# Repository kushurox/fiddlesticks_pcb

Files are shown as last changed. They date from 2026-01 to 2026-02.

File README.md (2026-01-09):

# Fiddle Sticks

**Fiddle Sticks** is a hobby flight controller (FC) project I designed using an **STM32F411** MCU and lightweight **coreless motors**. This is my personal project to learn PCB design and get hands-on experience with embedded development.

## About

- **MCU:** STM32F411
- **Motors:** 8520 Coreless DC (brushed)
- **Sensor:** ICM-45605 (symbol from SnapEDA — you will need to download it from SnapEDA if you want to use it)
- **Purpose:** Hobby learning project for PCB design, firmware development, and embedded systems

## Project Goals

1. Learn PCB design workflow.
2. Interface STM32F411 with coreless motors and sensors.
3. Flash my own **Rust-written firmware** onto the board in the future.
4. Experiment with flight controller concepts in a low-risk hobby setting.

## Notes

- This is **not a production-ready drone FC** — it’s purely for learning and experimentation.
- If you want to use the ICM-45605 footprint/symbol, please get it from **[SnapEDA](https://www.snapeda.com/)**.

## License

This project is open for learning purposes. Check the LICENSE file for details.

---

> Hobby project by [kushurox](https://github.com/kushurox).

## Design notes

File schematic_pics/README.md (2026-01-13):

# Schematic Pictures

This folder contains the schematic diagrams for the Fiddle Sticks project.

> **Note:** GitHub may cache SVG images in README, so sometimes the displayed image might be outdated.  
> Clicking on the **raw link** below will always open the latest version.

---

## Block Diagram

Block Diagram

[View Block Diagram (raw)](https://raw.githubusercontent.com/kushurox/fiddlesticks_pcb/main/schematic_pics/fiddlesticks.svg)

---

## Power Flow Diagram

Power Flow Diagram

[View Power Flow Diagram (raw)](https://raw.githubusercontent.com/kushurox/fiddlesticks_pcb/main/schematic_pics/fiddlesticks-VBAT_to_5V.svg)

---

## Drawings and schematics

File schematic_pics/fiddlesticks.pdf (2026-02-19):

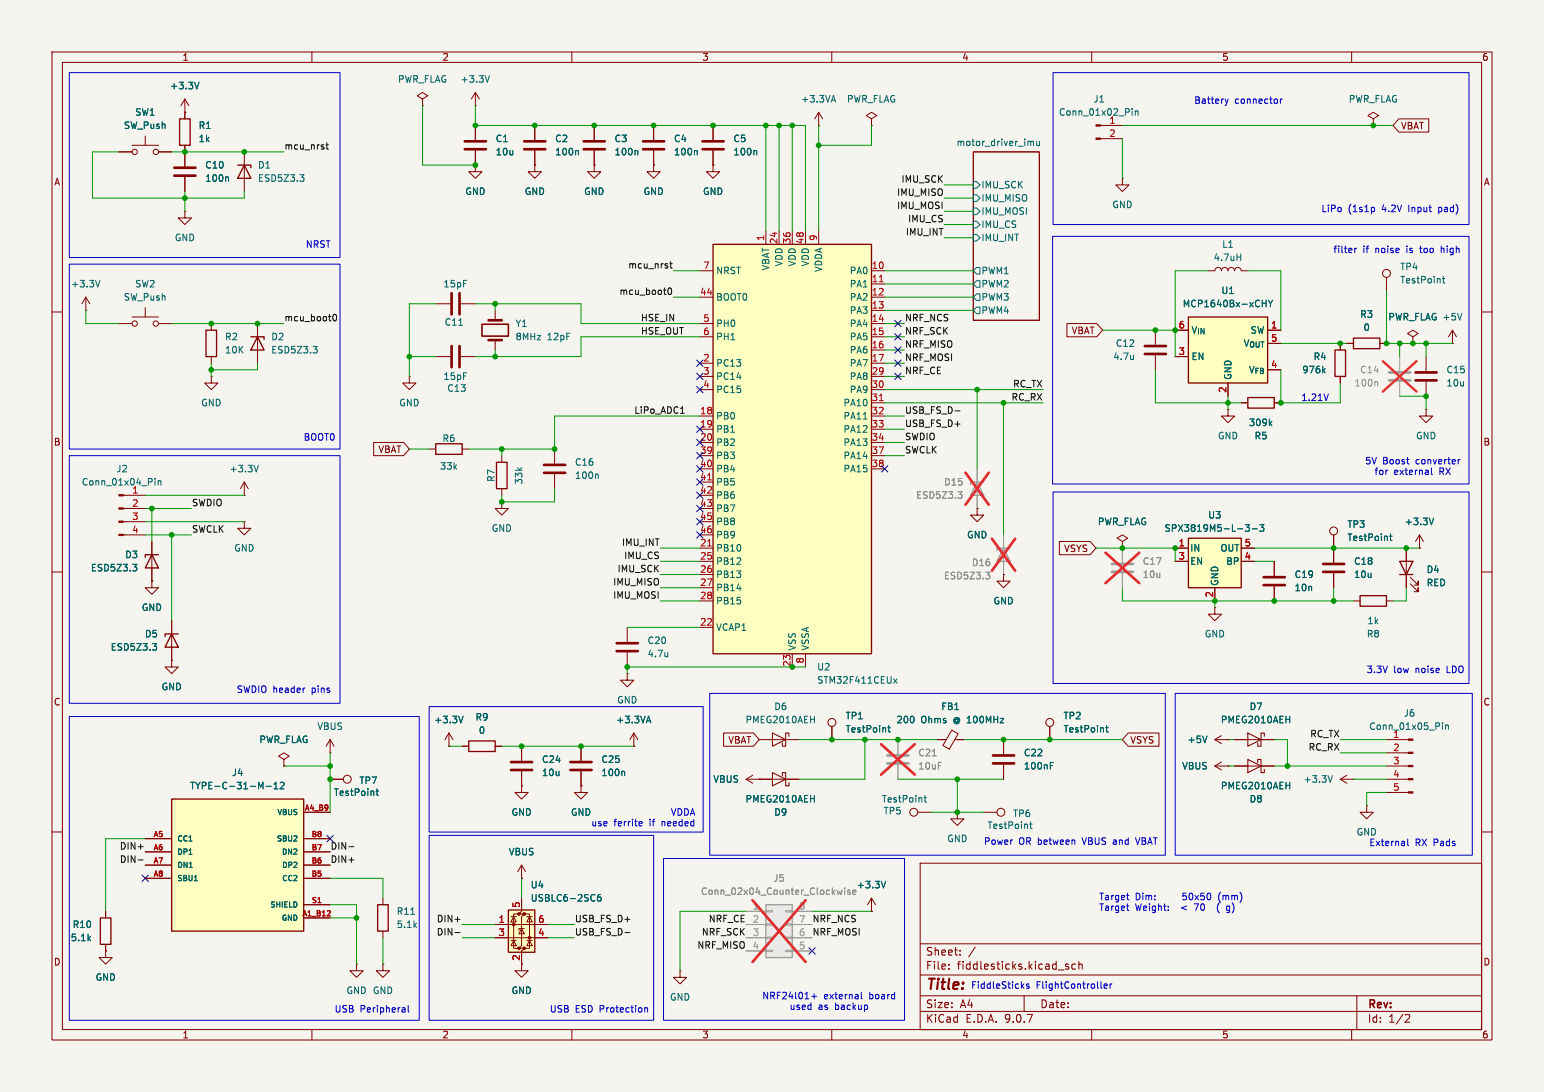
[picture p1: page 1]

LiPo (1s1p 4.2V Input pad) 5V Boost converter

1 VDD 24 VDD 36 VSS 23 VDD 48 VSSA

2 SW 1 V_{OUT} 5 V_{FB}4 U1 MCP1640Bx-xCHY

Id: 1/2 Title: File: fiddlesticks.kicad_sch Sheet: /

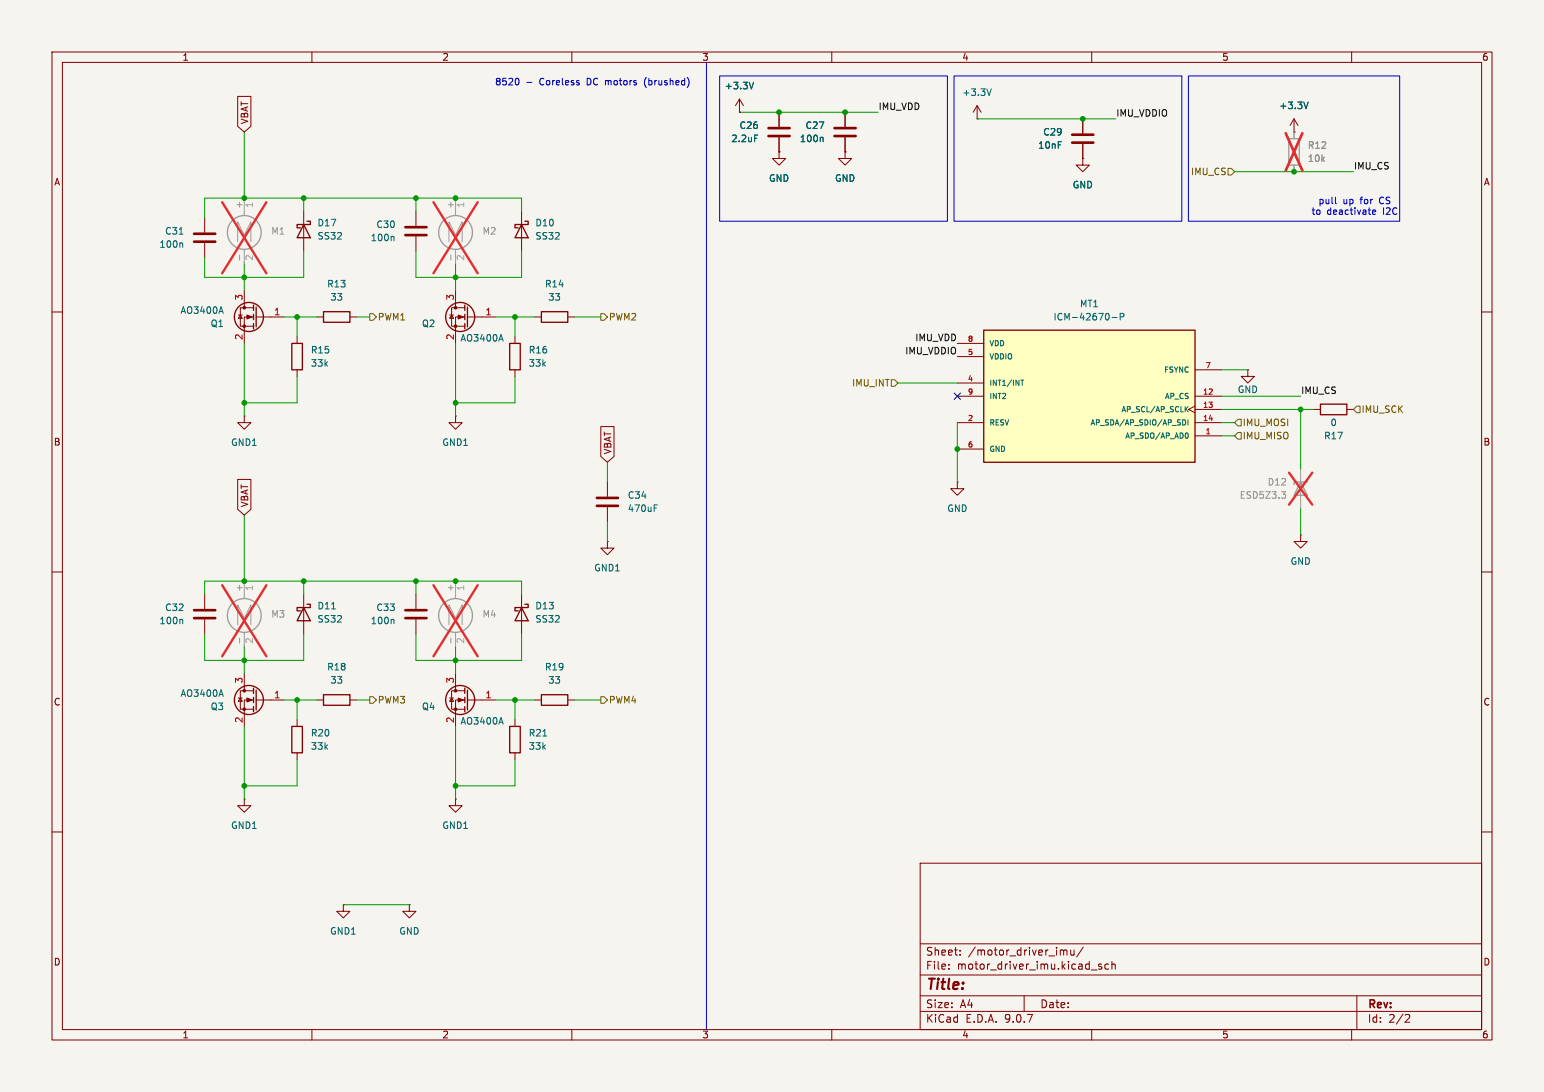
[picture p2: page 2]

pull up for CS

Id: 2/2 Title: File: motor_driver_imu.kicad_sch Sheet: /motor_driver_imu/ GND1 C30

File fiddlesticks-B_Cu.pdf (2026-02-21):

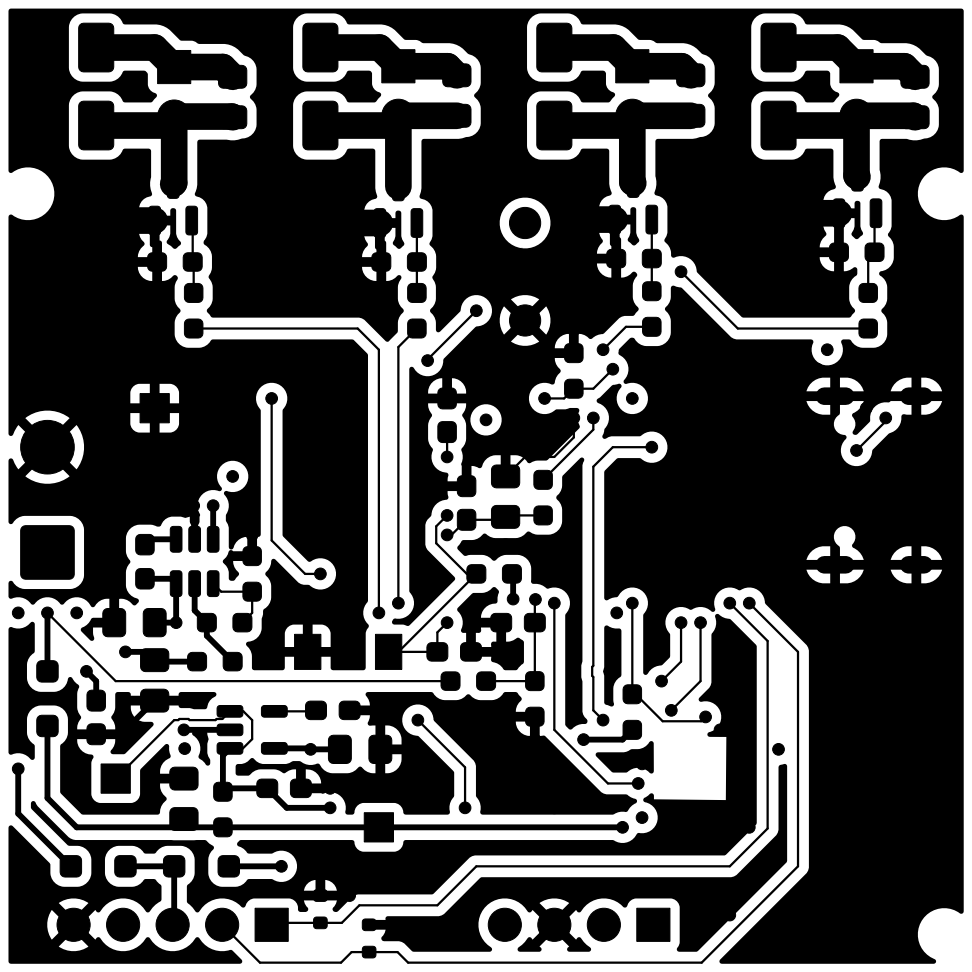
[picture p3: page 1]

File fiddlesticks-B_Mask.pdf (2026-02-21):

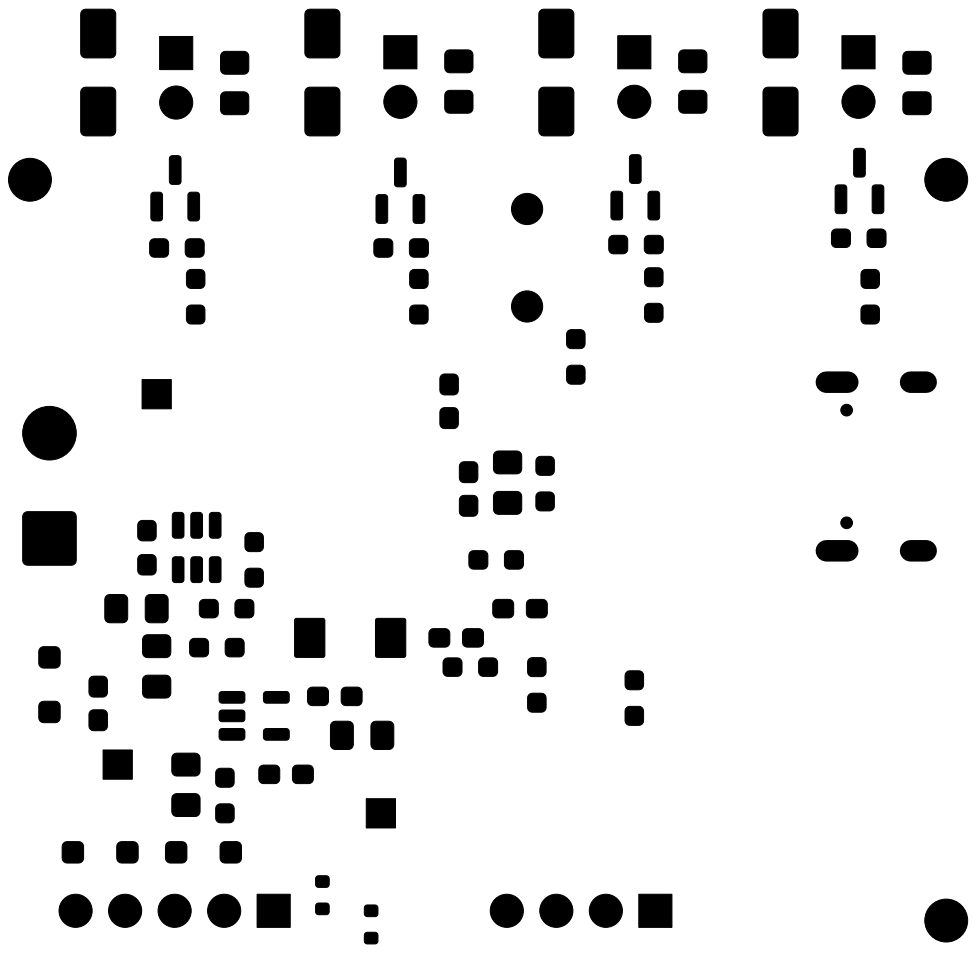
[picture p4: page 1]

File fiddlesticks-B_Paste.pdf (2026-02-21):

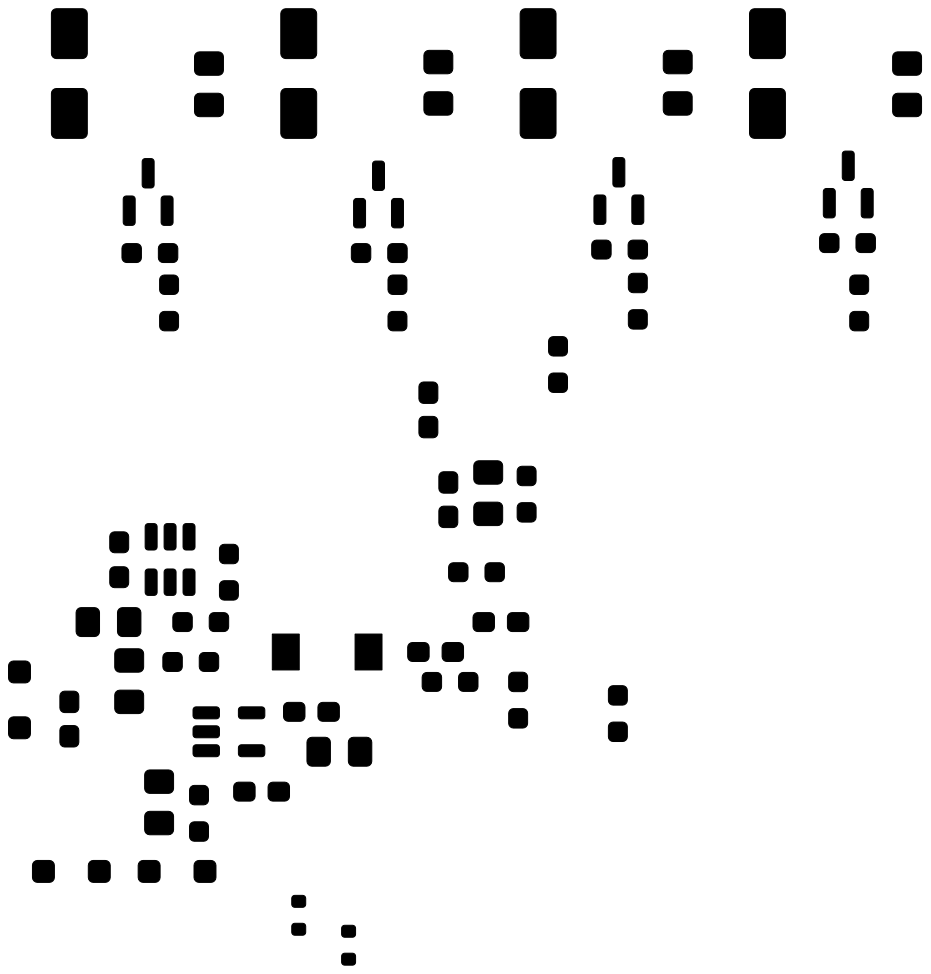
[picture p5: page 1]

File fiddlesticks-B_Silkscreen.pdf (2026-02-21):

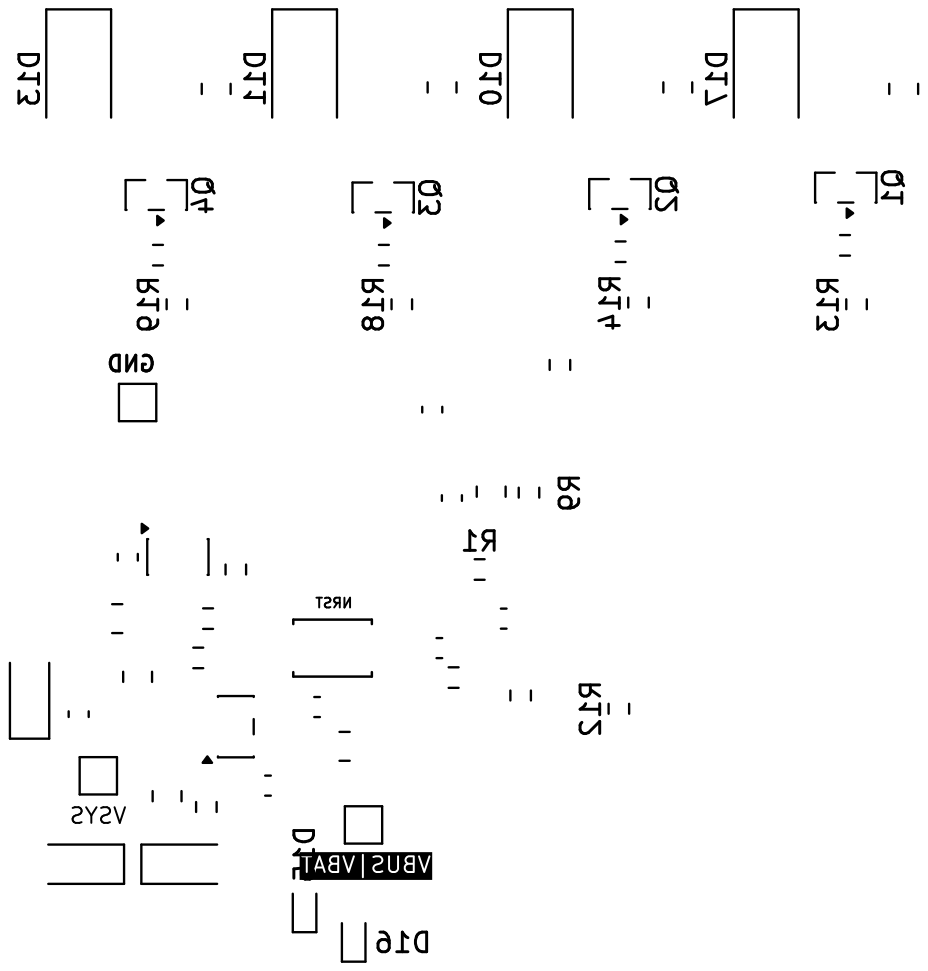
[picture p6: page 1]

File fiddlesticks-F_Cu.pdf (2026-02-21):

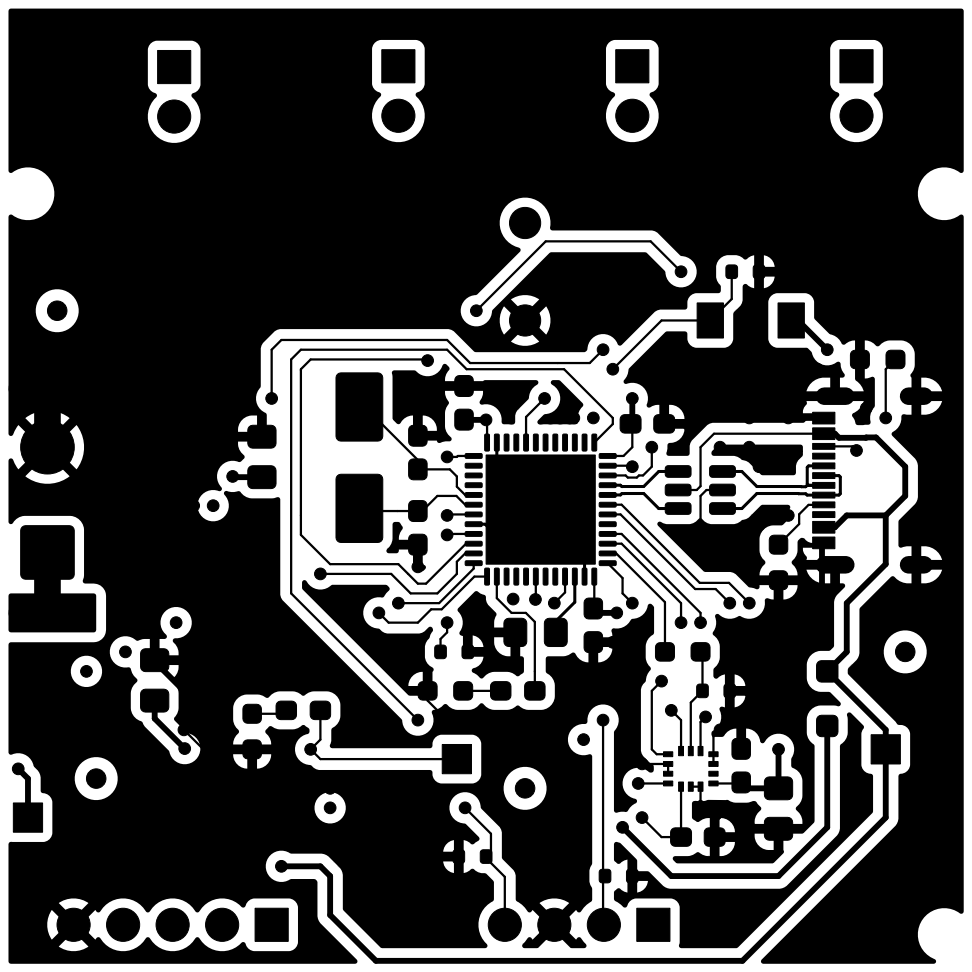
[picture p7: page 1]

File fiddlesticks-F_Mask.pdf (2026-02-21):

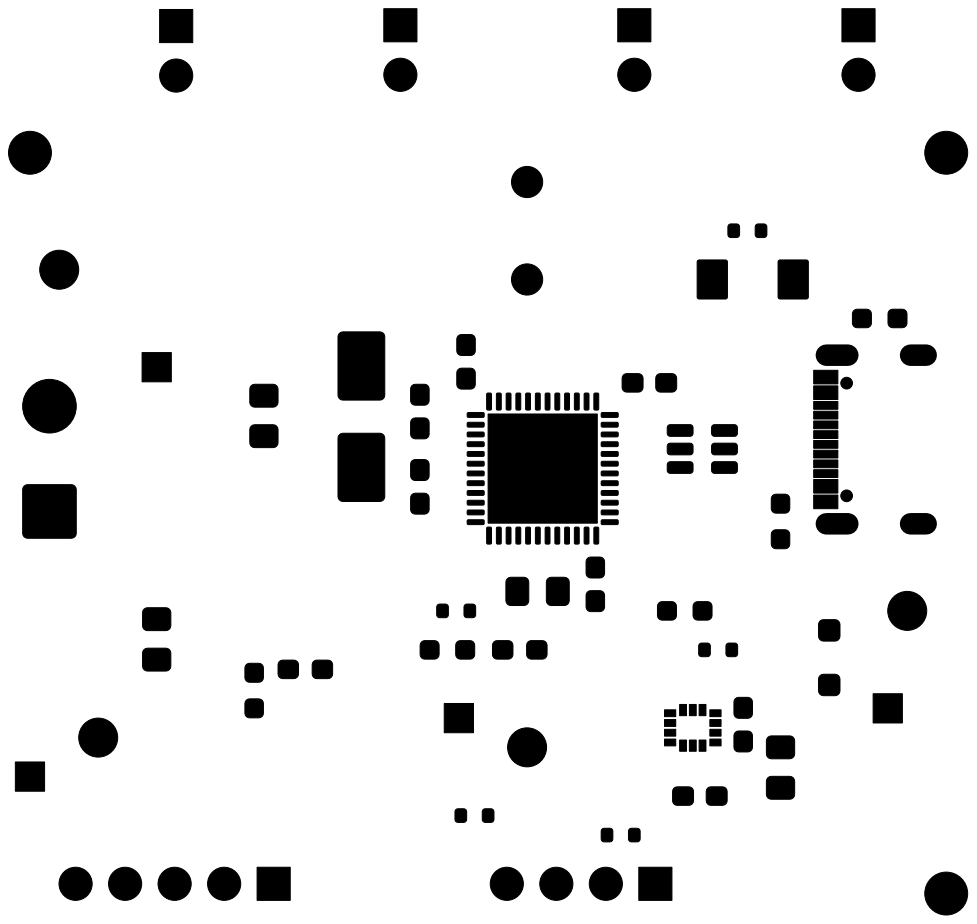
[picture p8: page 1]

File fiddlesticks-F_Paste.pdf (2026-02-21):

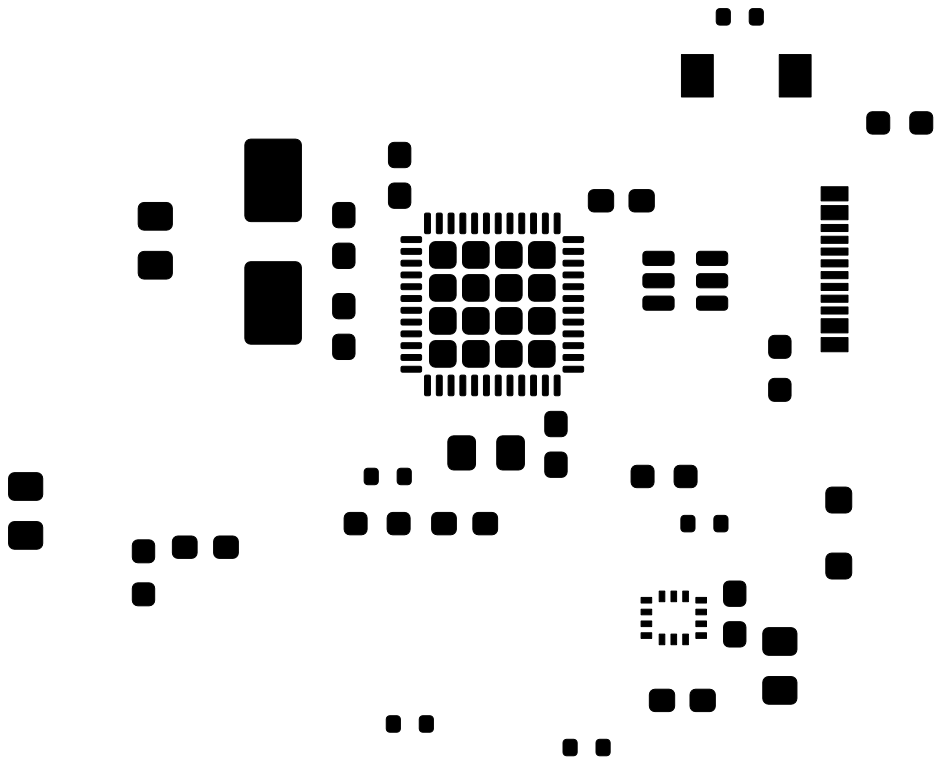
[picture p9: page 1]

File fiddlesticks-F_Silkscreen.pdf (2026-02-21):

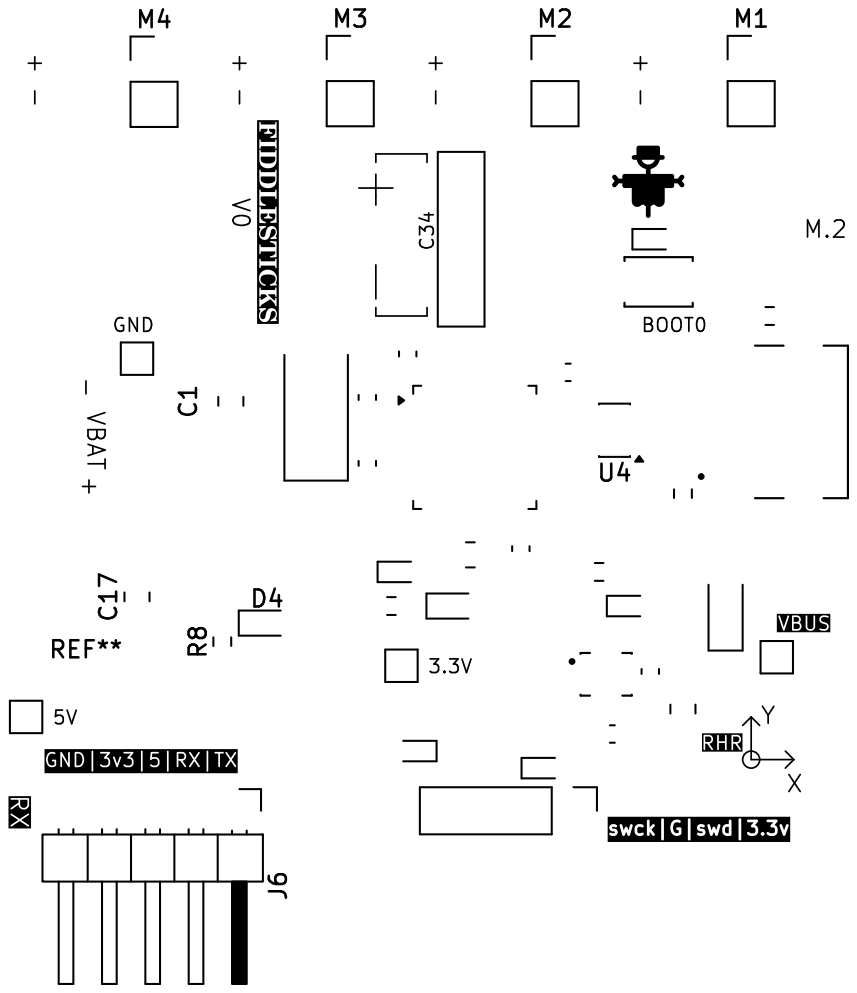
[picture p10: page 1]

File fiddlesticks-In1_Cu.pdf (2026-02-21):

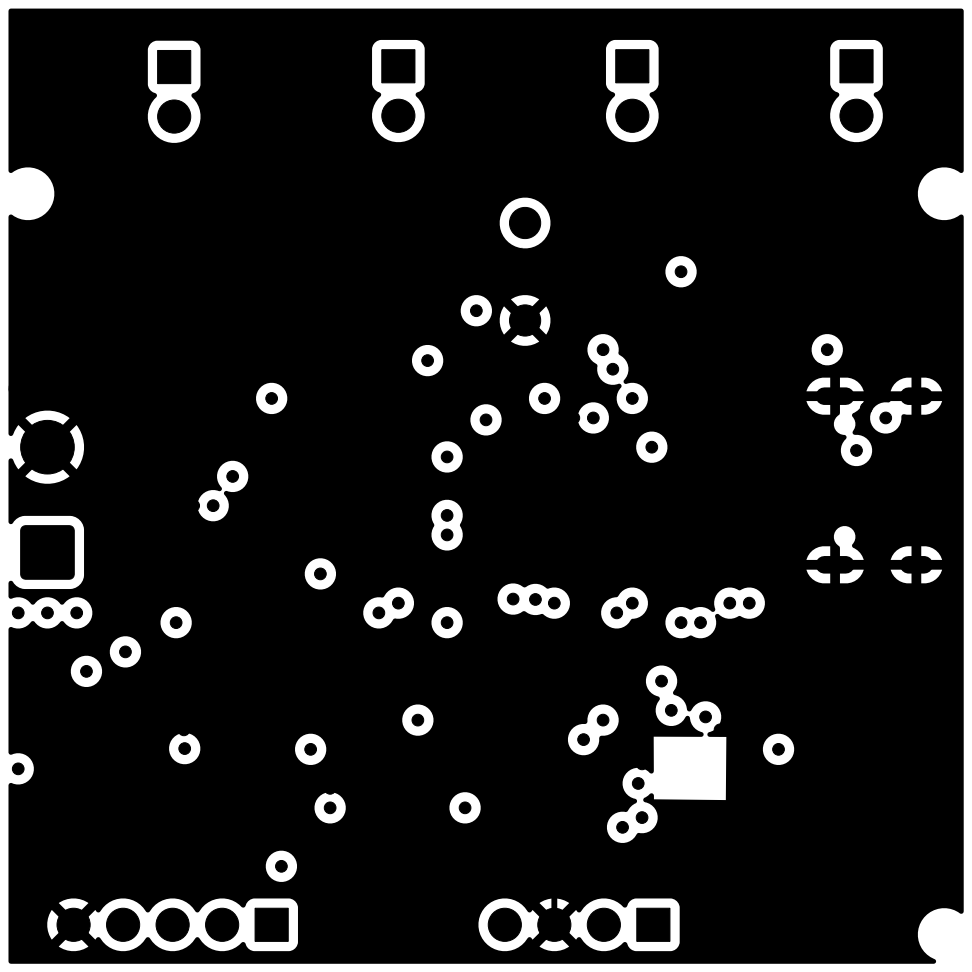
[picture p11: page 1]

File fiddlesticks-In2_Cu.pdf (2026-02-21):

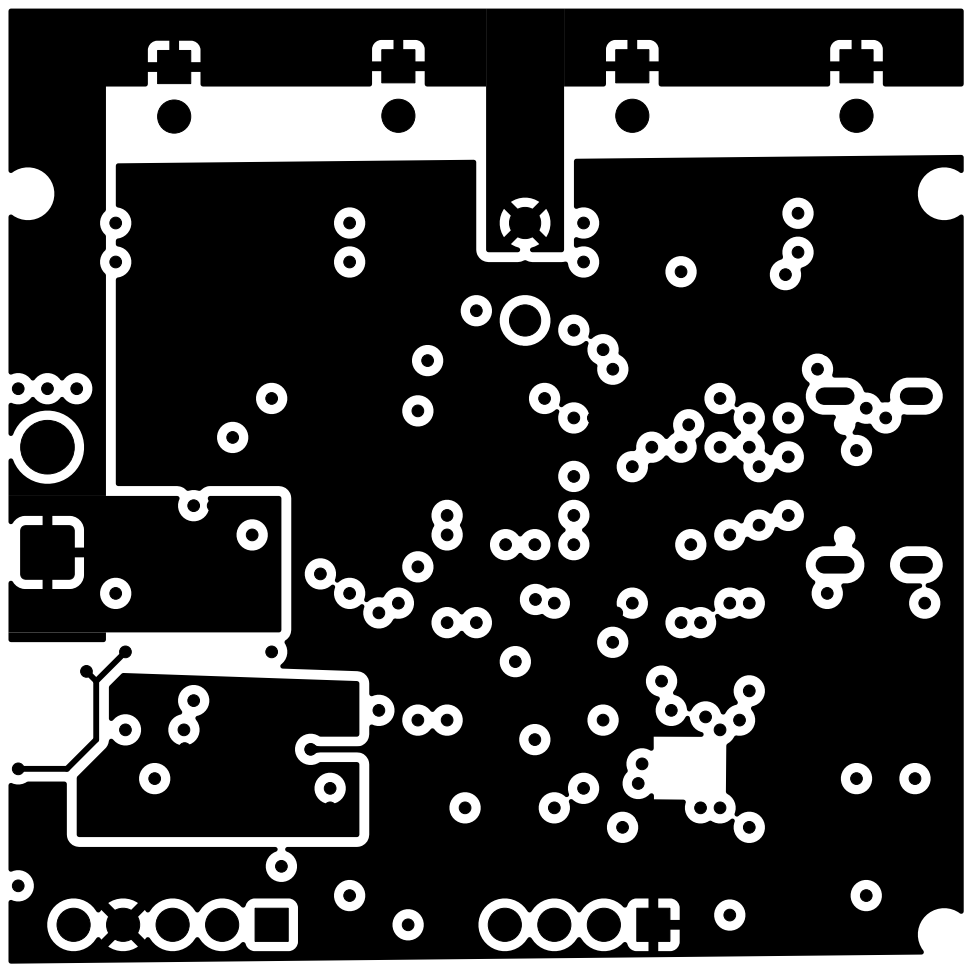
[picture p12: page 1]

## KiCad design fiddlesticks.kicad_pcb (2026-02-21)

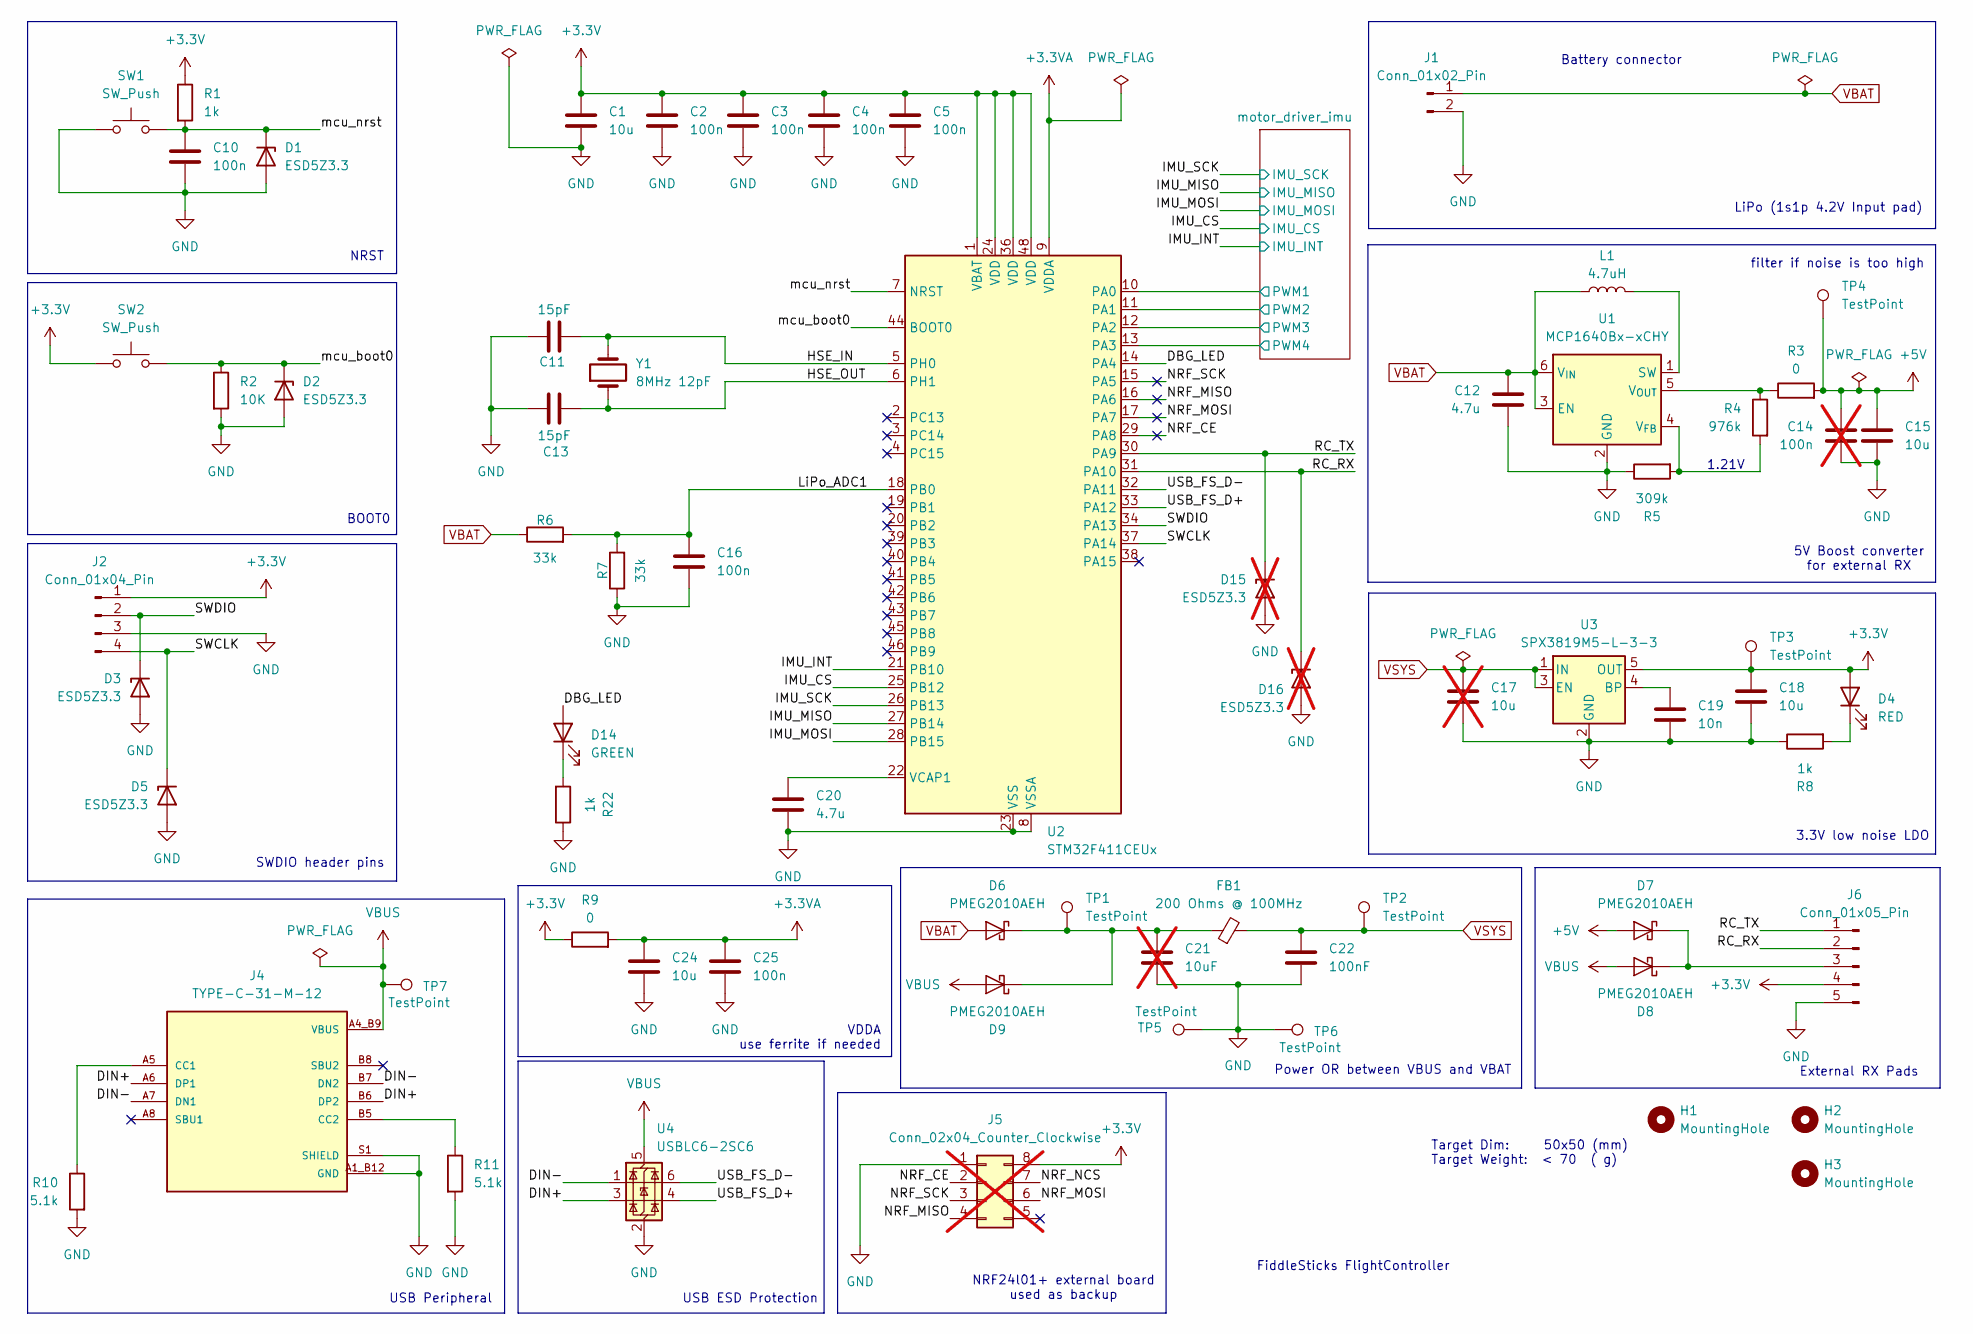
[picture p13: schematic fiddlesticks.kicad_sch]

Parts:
C1, C15, C18, C24: 10u; C_0805_2012Metric_Pad1.18x1.45mm_HandSolder
C2, C3, C4, C5, C10, C16, C25: 100n; C_0603_1608Metric_Pad1.08x0.95mm_HandSolder
C11, C13: 15pF; C_0603_1608Metric_Pad1.08x0.95mm_HandSolder
C12, C20: 4.7u; C_0805_2012Metric_Pad1.18x1.45mm_HandSolder
C14: 100n; C_0603_1608Metric_Pad1.08x0.95mm_HandSolder; not fitted
C17: 10u; C_0805_2012Metric_Pad1.18x1.45mm_HandSolder; not fitted
C19: 10n; C_0603_1608Metric_Pad1.08x0.95mm_HandSolder
C21: 10uF; C_0805_2012Metric_Pad1.18x1.45mm_HandSolder; not fitted
C22: 100nF; C_0603_1608Metric_Pad1.08x0.95mm_HandSolder
D1, D2, D3, D5: ESD5Z3.3; D_SOD-523
D4: RED; LED_0603_1608Metric_Pad1.05x0.95mm_HandSolder
D6, D7, D8, D9: PMEG2010AEH; D_SOD-123F
D14: GREEN; LED_0603_1608Metric_Pad1.05x0.95mm_HandSolder
D15, D16: ESD5Z3.3; D_SOD-523; not fitted
FB1: 200 Ohms @ 100MHz; R_0603_1608Metric_Pad0.98x0.95mm_HandSolder
H1, H2, H3: MountingHole; MountingHole_2.2mm_M2
J1: Conn_01x02_Pin; SolderWire-1sqmm_1x02_P5.4mm_D1.4mm_OD2.7mm
J2: Conn_01x04_Pin; PinHeader_1x04_P2.54mm_Vertical
J4: TYPE-C-31-M-12; HRO_TYPE-C-31-M-12; PARTREV 2020.12.08
J5: Conn_02x04_Counter_Clockwise; PinSocket_2x04_P2.54mm_Vertical; not fitted
J6: Conn_01x05_Pin; PinHeader_1x05_P2.54mm_Horizontal
L1: 4.7uH; L_0603_1608Metric_Pad1.05x0.95mm_HandSolder; MPN LQM18PN4R7MFRL
R1, R8, R22: 1k; R_0603_1608Metric_Pad0.98x0.95mm_HandSolder
R2: 10K; R_0603_1608Metric_Pad0.98x0.95mm_HandSolder
R3, R9: 0; R_0603_1608Metric_Pad0.98x0.95mm_HandSolder
R4: 976k; R_0603_1608Metric_Pad0.98x0.95mm_HandSolder
R5: 309k; R_0603_1608Metric_Pad0.98x0.95mm_HandSolder
R6, R7: 33k; R_0603_1608Metric_Pad0.98x0.95mm_HandSolder
R10, R11: 5.1k; R_0603_1608Metric_Pad0.98x0.95mm_HandSolder
SW1, SW2: SW_Push; SW_TS-1088-AR02016; MPN TS-1088-AR02016
TP1, TP2, TP3, TP4, TP5, TP6, TP7: TestPoint; TestPoint_Pad_1.5x1.5mm
U1: MCP1640Bx-xCHY; SOT-23-6
U2: STM32F411CEUx; QFN-48-1EP_7x7mm_P0.5mm_EP5.6x5.6mm
U3: SPX3819M5-L-3-3; SOT-23-5
U4: USBLC6-2SC6; SOT-23-6
Y1: 8MHz 12pF; Crystal_SMD_5032-2Pin_5.0x3.2mm_HandSoldering

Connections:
+3.3V: C1.1, C2.1, C3.1, C4.1, C5.1, C18.1, D4.2 (A), J2.1, J5.8, J6.4, R1.1, R9.1, SW2.1, TP3.1, U2.1 (VBAT), U2.24 (VDD), U2.36 (VDD), U2.48 (VDD), U3.5 (OUT); also elsewhere on the board
+3.3VA: C24.1, C25.1, R9.2, U2.9 (VDDA)
+5V: C14.1, C15.1, D7.2 (A), R3.2, TP4.1
/DBG_LED: D14.2 (A), U2.14 (PA4)
/DIN+: J4.A6 (DP1), J4.B6 (DP2), U4.3 (I/O2)
/DIN-: J4.A7 (DN1), J4.B7 (DN2), U4.1 (I/O1)
/HSE_IN: C11.1, U2.5 (PH0), Y1.2
/HSE_OUT: C13.2, U2.6 (PH1), Y1.1
/IMU_CS: U2.25 (PB12); also elsewhere on the board
/IMU_INT: U2.21 (PB10); also elsewhere on the board
/IMU_MISO: U2.27 (PB14); also elsewhere on the board
/IMU_MOSI: U2.28 (PB15); also elsewhere on the board
/IMU_SCK: U2.26 (PB13); also elsewhere on the board
/LiPo_ADC1: C16.1, R6.2, R7.2, U2.18 (PB0)
/NRF_CE: J5.2, U2.29 (PA8)
/NRF_MISO: J5.4, U2.16 (PA6)
/NRF_MOSI: J5.6, U2.17 (PA7)
/NRF_SCK: J5.3, U2.15 (PA5)
/RC_RX: D16.1 (K), J6.2, U2.31 (PA10)
/RC_TX: D15.1 (K), J6.1, U2.30 (PA9)
/SWCLK: D5.1 (K), J2.4, U2.37 (PA14)
/SWDIO: D3.1 (K), J2.2, U2.34 (PA13)
/USB_FS_D+: U2.33 (PA12), U4.4 (I/O2)
/USB_FS_D-: U2.32 (PA11), U4.6 (I/O1)
/mcu_boot0: D2.1 (K), R2.1, SW2.2, U2.44 (BOOT0)
/mcu_nrst: C10.1, D1.1 (K), R1.2, SW1.2, U2.7 (NRST)
/motor_driver_imu/PWM1: U2.10 (PA0); also elsewhere on the board
/motor_driver_imu/PWM2: U2.11 (PA1); also elsewhere on the board
/motor_driver_imu/PWM3: U2.12 (PA2); also elsewhere on the board
/motor_driver_imu/PWM4: U2.13 (PA3); also elsewhere on the board
GND: C1.2, C2.2, C3.2, C4.2, C5.2, C10.2, C11.2, C12.2, C13.1, C14.2, C15.2, C16.2, C17.2, C18.2, C19.2, C20.2, C21.2, C22.2, C24.2, C25.2, D1.2 (A), D2.2 (A), D3.2 (A), D5.2 (A), D15.2 (A), D16.2 (A), J1.2, J2.3, J4.A1_B12 (GND), J4.B1_A12 (GND), J4.S1 (SHIELD), J4.S2 (SHIELD), J4.S3 (SHIELD), J4.S4 (SHIELD), J5.1, J6.5, R2.2, R5.1, R7.1, R8.1, R10.2, R11.2, R22.1, SW1.1, TP5.1, TP6.1, U1.2 (GND), U2.8 (VSSA), U2.23 (VSS), U2.35 (VSS), U2.47 (VSS), U2.49 (VSS), U3.2 (GND), U4.2 (GND); also elsewhere on the board
unnamed: D4.1 (K), R8.2
unnamed: C21.1, D6.1 (K), D9.1 (K), FB1.1, TP1.1
unnamed: D7.1 (K), D8.1 (K), J6.3
unnamed: D14.1 (K), R22.2
unnamed: J4.A5 (CC1), R10.1
unnamed: J4.B5 (CC2), R11.1
unnamed: L1.2, U1.1 (SW)
unnamed: R4.2, R5.2, U1.4 (V_{FB})
unnamed: R3.1, R4.1, U1.5 (V_{OUT})
unnamed: C20.1, U2.22 (VCAP1)
unnamed: C19.1, U3.4 (BP)
VBAT: C12.1, D6.2 (A), J1.1, L1.1, R6.1, U1.3 (EN), U1.6 (V_{IN}); also elsewhere on the board
VBUS: D8.2 (A), D9.2 (A), J4.A4_B9 (VBUS), J4.B4_A9 (VBUS), TP7.1, U4.5 (VBUS)
VSYS: C17.1, C22.1, FB1.2, TP2.1, U3.1 (IN), U3.3 (EN)

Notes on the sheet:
LiPo (1s1p 4.2V Input pad)
USB Peripheral
3.3V low noise LDO
SWDIO header pins
USB ESD Protection
External RX Pads
NRF24l01+ external board used as backup
5V Boost converter for external RX
1.21V
NRST
Power OR between VBUS and VBAT
FiddleSticks FlightController
Target Dim: 50x50 (mm) Target Weight: < 70 ( g)
filter if noise is too high
Battery connector
VDDA use ferrite if needed
BOOT0

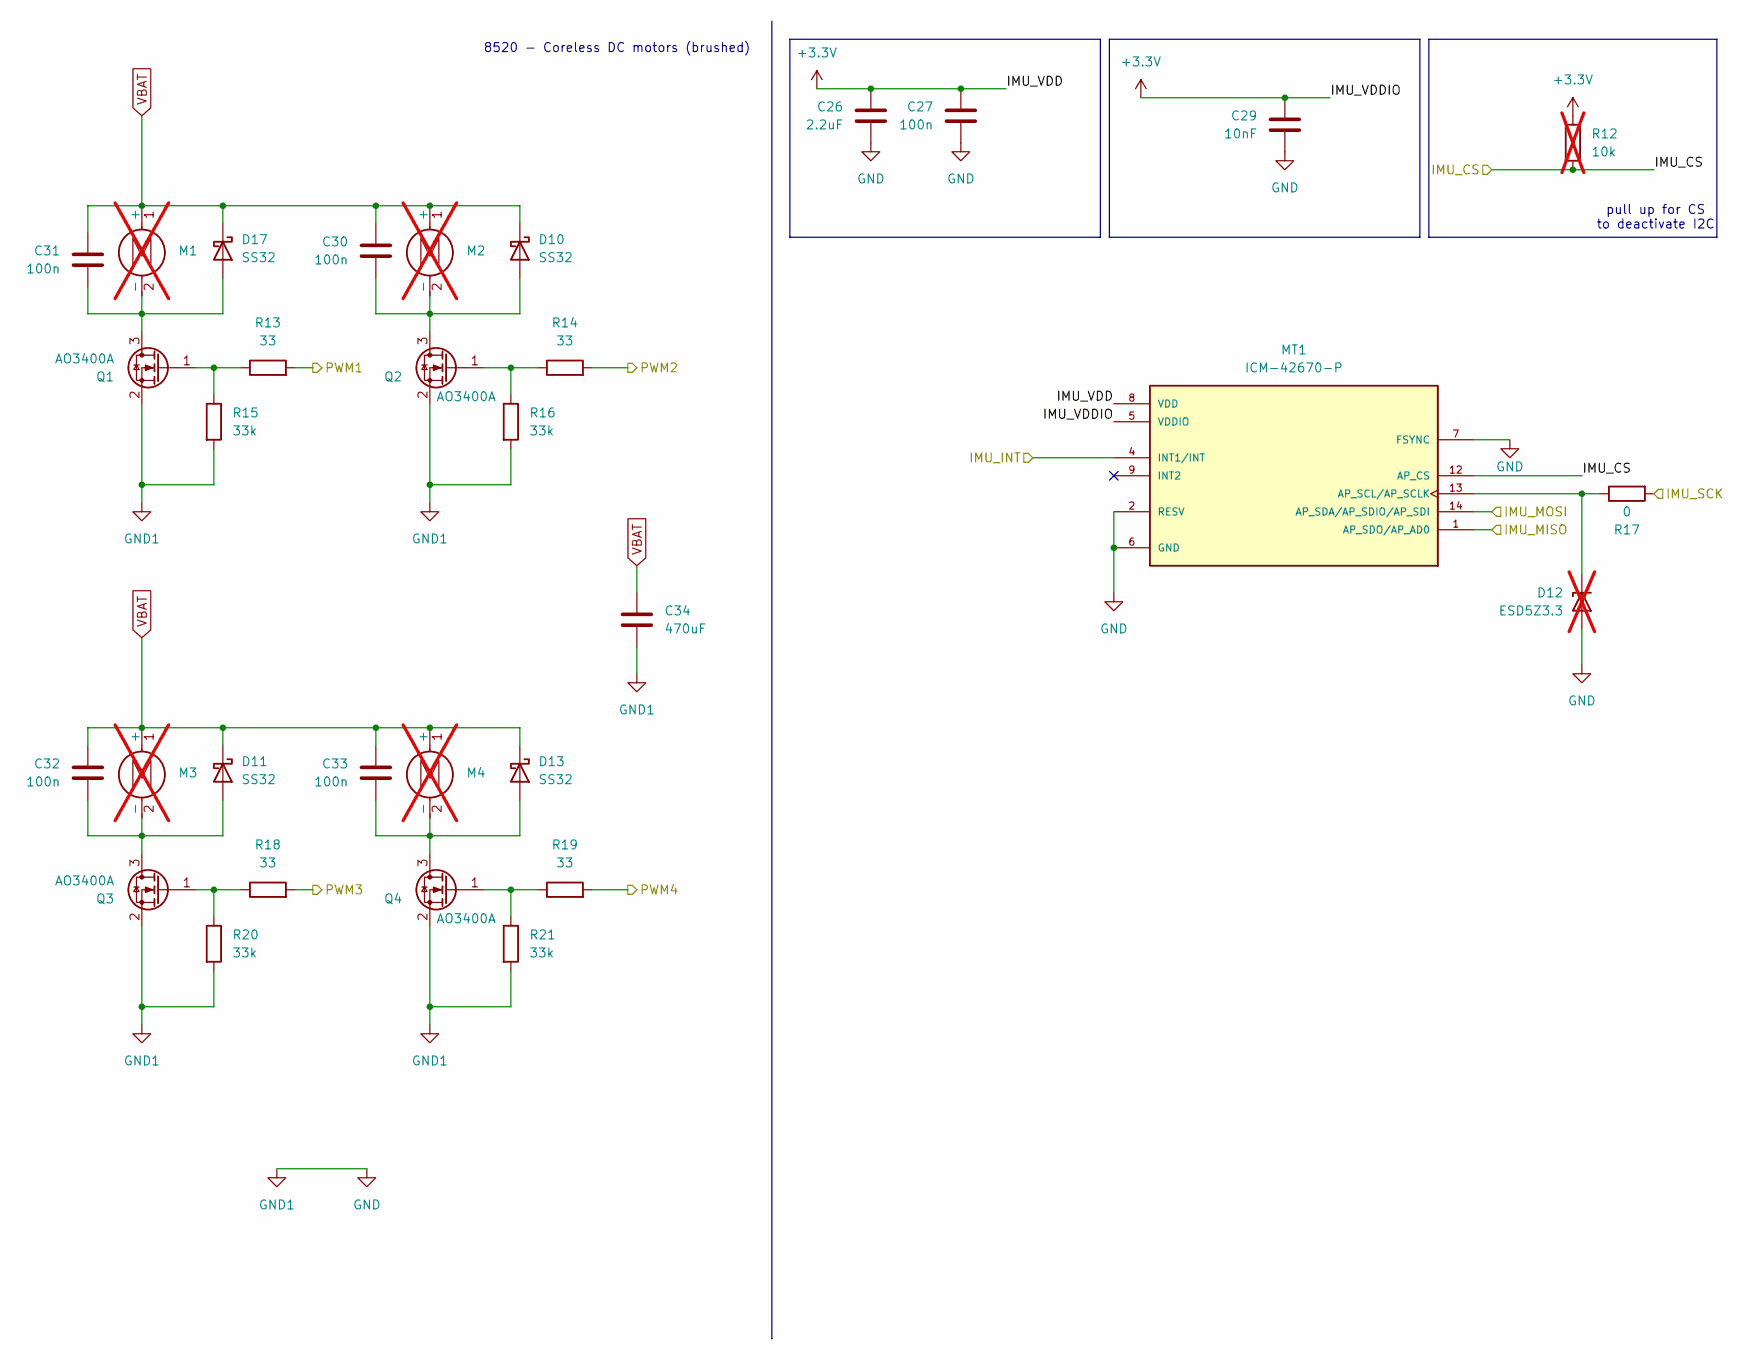
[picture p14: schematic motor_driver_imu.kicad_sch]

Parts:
C26: 2.2uF; C_0805_2012Metric_Pad1.18x1.45mm_HandSolder
C27: 100n; C_0603_1608Metric_Pad1.08x0.95mm_HandSolder
C29: 10nF; C_0603_1608Metric_Pad1.08x0.95mm_HandSolder
C30, C31, C32, C33: 100n; C_0805_2012Metric_Pad1.18x1.45mm_HandSolder
C34: 470uF; C_Disc_D10.0mm_W2.5mm_P5.00mm; MPN 35YXJ470M10x16
D10, D11, D13, D17: SS32; D_SMA
D12: ESD5Z3.3; D_SOD-523; not fitted
M1, M2, M3, M4: Motor_DC; PinHeader_1x02_P2.54mm_Vertical; not fitted
MT1: ICM-42670-P; XDCR_ICM-42670-P; PARTREV 1.1
Q1, Q2, Q3, Q4: AO3400A; SOT-23
R12: 10k; R_0603_1608Metric_Pad0.98x0.95mm_HandSolder; not fitted
R13, R14, R18, R19: 33; R_0603_1608Metric_Pad0.98x0.95mm_HandSolder
R15, R16, R20, R21: 33k; R_0603_1608Metric_Pad0.98x0.95mm_HandSolder
R17: 0; R_0603_1608Metric_Pad0.98x0.95mm_HandSolder

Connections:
+3.3V: C26.1, C27.1, C29.1, MT1.5 (VDDIO), MT1.8 (VDD), R12.2; also elsewhere on the board
/IMU_CS: MT1.12 (AP_CS), R12.1; also elsewhere on the board
/IMU_INT: MT1.4 (INT1/INT); also elsewhere on the board
/IMU_MISO: MT1.1 (AP_SDO/AP_AD0); also elsewhere on the board
/IMU_MOSI: MT1.14 (AP_SDA/AP_SDIO/AP_SDI); also elsewhere on the board
/IMU_SCK: R17.2; also elsewhere on the board
/motor_driver_imu/PWM1: R13.2; also elsewhere on the board
/motor_driver_imu/PWM2: R14.2; also elsewhere on the board
/motor_driver_imu/PWM3: R18.2; also elsewhere on the board
/motor_driver_imu/PWM4: R19.2; also elsewhere on the board
GND: C26.2, C27.2, C29.2, C34.2, D12.2 (A), MT1.2 (RESV), MT1.3 (RESV), MT1.6 (GND), MT1.7 (FSYNC), MT1.10 (RESV), MT1.11 (RESV), Q1.2 (S), Q2.2 (S), Q3.2 (S), Q4.2 (S), R15.2, R16.2, R20.2, R21.2; also elsewhere on the board
unnamed: C30.2, D10.2 (A), M2.2 (-), Q2.3 (D)
unnamed: C32.2, D11.2 (A), M3.2 (-), Q3.3 (D)
unnamed: D12.1 (K), MT1.13 (AP_SCL/AP_SCLK), R17.1
unnamed: C33.2, D13.2 (A), M4.2 (-), Q4.3 (D)
unnamed: C31.2, D17.2 (A), M1.2 (-), Q1.3 (D)
unnamed: Q1.1 (G), R13.1, R15.1
unnamed: Q2.1 (G), R14.1, R16.1
unnamed: Q3.1 (G), R18.1, R20.1
unnamed: Q4.1 (G), R19.1, R21.1
VBAT: C30.1, C31.1, C32.1, C33.1, C34.1, D10.1 (K), D11.1 (K), D13.1 (K), D17.1 (K), M1.1 (+), M2.1 (+), M3.1 (+), M4.1 (+); also elsewhere on the board

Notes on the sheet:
8520 - Coreless DC motors (brushed)
pull up for CS to deactivate I2C

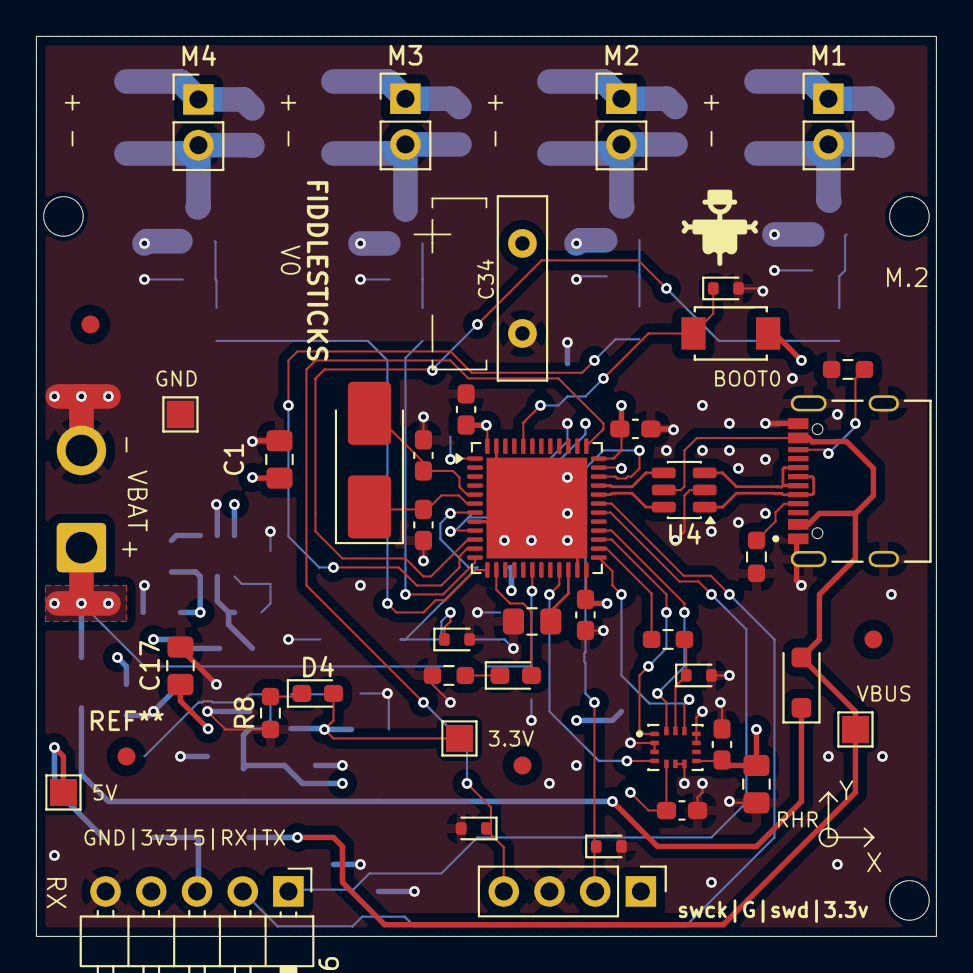
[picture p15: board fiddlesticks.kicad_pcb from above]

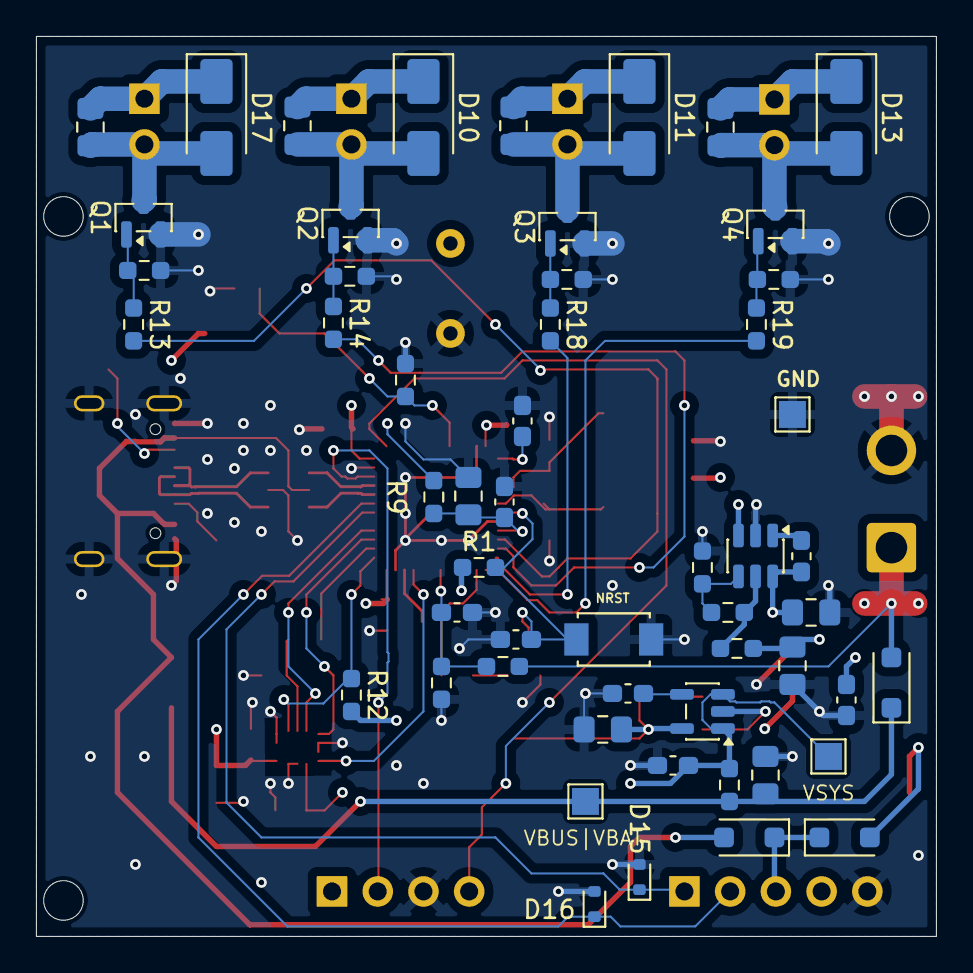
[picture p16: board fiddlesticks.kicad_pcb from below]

Board: 4 copper layers, 50.0 x 50.0 mm, 99 parts (54 on the bottom side), 50 nets.

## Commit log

2026-01-06 added svg of current sch
2026-01-06 changed diodes for power ORing
    [fiddlesticks.kicad_sch, vbat_two_5v.kicad_sch]
2026-01-06 added battery connector
    [fiddlesticks.kicad_sch]
2026-01-07 assigned footprints
    [fiddlesticks.kicad_sch, vbat_two_5v.kicad_sch]
2026-01-07 Marked nrf connector as DNP
2026-01-09 revised schematic
    [fiddlesticks.kicad_sch, motor_driver_imu.kicad_sch, vbat_two_5v.kicad_sch]
2026-01-09 updated sch plotsgi
    [fiddlesticks.kicad_sch]
2026-01-13 added 3.3 header for rx and changed flywheel diodes
    [fiddlesticks.kicad_sch, motor_driver_imu.kicad_sch]
2026-01-13 updated schematic pics
2026-01-14 updated footprints and changed crystal
    [fiddlesticks.kicad_sch, motor_driver_imu.kicad_sch]
2026-02-17 added bulk cap near motors, started pcb layout routing
    [TYPE-C-31-M-12.step, fiddlesticks.kicad_pcb, fiddlesticks.kicad_sch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]
2026-02-17 routed some more things
    [fiddlesticks.kicad_pcb, motor_driver_imu.kicad_sch]
2026-02-18 finished routing
    [TYPE-C-31-M-12.step, fiddlesticks.kicad_pcb, fiddlesticks.kicad_sch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]
2026-02-19 fixed usb routing, and esd/pull ups/pull downs placement
    [fiddlesticks.kicad_pcb, fiddlesticks.kicad_sch]
2026-02-19 added vias under MCU, added silk screen for SWD
    [fiddlesticks.kicad_pcb, fiddlesticks.kicad_sch]
2026-02-21 fixed some more routing
    [fiddlesticks.kicad_pcb, fiddlesticks.kicad_sch]
